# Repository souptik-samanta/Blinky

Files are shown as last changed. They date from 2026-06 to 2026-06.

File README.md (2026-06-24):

# Blinky Board

Made by Souptik!

I built this little project because I wanted a heart-shaped PCB that I could gift to someone. It's a simple LED chaser built around a 555 timer and a CD4017 decade counter. The LEDs light up one after another, creating a blinking animation around the heart.

Built using parts I already had on hand, and manufactured through JLC thanks stasis.
BUILD PHOTO


and here is the bottom



worknig video 

https://youtube.com/shorts/QsSJmAaTk8Q?feature=share
## Photos

Blinky Board PCB

Blinky Board Schematic

Blinky Board PCB Layout

Blinky Board Render

## How It Works

A 555 timer is configured as an oscillator that generates clock pulses. These pulses are fed into a CD4017 decade counter, which turns on one output at a time. Each output drives an LED on the heart, creating a rotating blinking effect. The potentiometer can be adjusted to change the animation speed.

## Bill of Materials (BoM)

| Part | Purpose | Quantity |
|---|---|---|
| PCB | Heart-shaped board that holds all the components | 1 |
| LED | Creates the chasing light effect around the heart | 10 |
| 1kΩ Resistor | Helps set the oscillator timing | 1 |
| 470Ω Resistor | Limits LED current | 1 |
| Potentiometer (RV) | Adjusts the animation speed | 1 |
| 1µF Capacitor | Works with the 555 timer to generate clock pulses | 1 |
| 1x01 Header | Test/debug connection point | 1 |
| 1x02 Header | Power input connector | 1 |
| CD4017 | Sequences the LEDs one after another | 1 |
| NE555P | Generates the clock signal | 1 |

## Cost

All components were sourced from my existing parts inventory, so the project itself cost me nothing to assemble.

| Item | Cost (USD) |
|---|---|
| Components | $0.00 |
| PCB | JLC sponser |
| **Total Out-of-Pocket Cost** | **$0.00** |

## Why I Made It

I wanted to make something small, simple, and fun that could be gifted to someone. Instead of a regular rectangular PCB, I designed it in the shape of a heart and added a classic 555 + 4017 LED chaser circuit to make it feel a bit more special.

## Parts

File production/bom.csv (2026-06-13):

Designator | Footprint | Quantity | Value | LCSC Part #
C1 | CP_Radial_D5.0mm_P2.50mm | 1 | 100uF
C2 | C_Disc_D4.7mm_W2.5mm_P5.00mm | 1 | 0.1uF
D1, D10, D2, D3, D4, D5, D6, D7, D8, D9 | LED_D5.0mm | 10 | LED
J1 | PinSocket_1x02_P2.54mm_Vertical | 1 | Conn_01x02_Pin
R1 | R_Axial_DIN0207_L6.3mm_D2.5mm_P7.62mm_Horizontal | 1 | R
R2 | R_Axial_DIN0207_L6.3mm_D2.5mm_P7.62mm_Horizontal | 1 | 470
RV1 | Potentiometer_Vishay_T93YA_Vertical | 1 | R_Potentiometer
U1 | DIP-16_W7.62mm_LongPads | 1 | 4017
U2 | DIP-8_W7.62mm_LongPads | 1 | NE555P

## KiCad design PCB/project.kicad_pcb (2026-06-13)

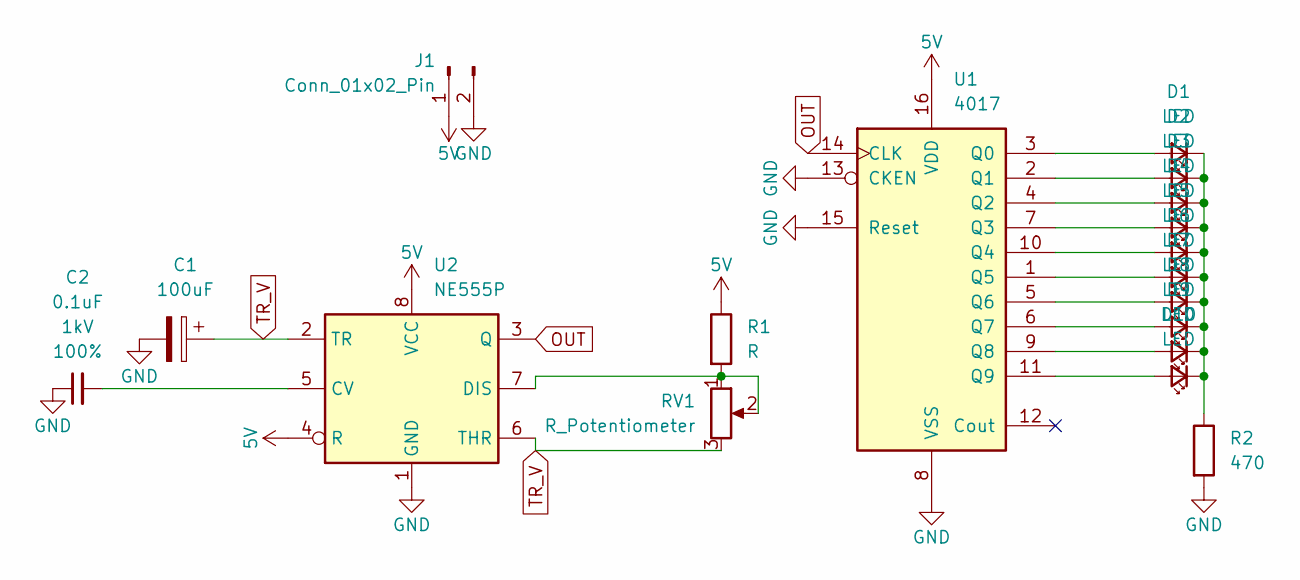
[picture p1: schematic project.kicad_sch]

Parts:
C1: 100uF; CP_Radial_D5.0mm_P2.50mm
C2: 0.1uF; C_Disc_D4.7mm_W2.5mm_P5.00mm; Voltage 1kV; Tolerance 100%
D1, D2, D3, D4, D5, D6, D7, D8, D9, D10: LED; LED_D5.0mm
J1: Conn_01x02_Pin; PinSocket_1x02_P2.54mm_Vertical
R1: R; R_Axial_DIN0207_L6.3mm_D2.5mm_P7.62mm_Horizontal
R2: 470; R_Axial_DIN0207_L6.3mm_D2.5mm_P7.62mm_Horizontal
RV1: R_Potentiometer; Potentiometer_Vishay_T93YA_Vertical
U1: 4017; DIP-16_W7.62mm_LongPads
U2: NE555P; DIP-8_W7.62mm_LongPads

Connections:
5V: J1.1, R1.1, U1.16 (VDD), U2.4 (R), U2.8 (VCC)
GND: C1.2, C2.1, J1.2, R2.2, U1.8 (VSS), U1.13 (CKEN), U1.15 (Reset), U2.1 (GND)
unnamed: D1.2 (A), U1.3 (Q0)
unnamed: D1.1 (K), D2.1 (K), D3.1 (K), D4.1 (K), D5.1 (K), D6.1 (K), D7.1 (K), D8.1 (K), D9.1 (K), D10.1 (K), R2.1
unnamed: D2.2 (A), U1.2 (Q1)
unnamed: D3.2 (A), U1.4 (Q2)
unnamed: D4.2 (A), U1.7 (Q3)
unnamed: D5.2 (A), U1.10 (Q4)
unnamed: D6.2 (A), U1.1 (Q5)
unnamed: D7.2 (A), U1.5 (Q6)
unnamed: D8.2 (A), U1.6 (Q7)
unnamed: D9.2 (A), U1.9 (Q8)
unnamed: D10.2 (A), U1.11 (Q9)
unnamed: C2.2, U2.5 (CV)
unnamed: R1.2, RV1.1, RV1.2, U2.7 (DIS)
OUT: U1.14 (CLK), U2.3 (Q)
TR_V: C1.1, RV1.3, U2.2 (TR), U2.6 (THR)

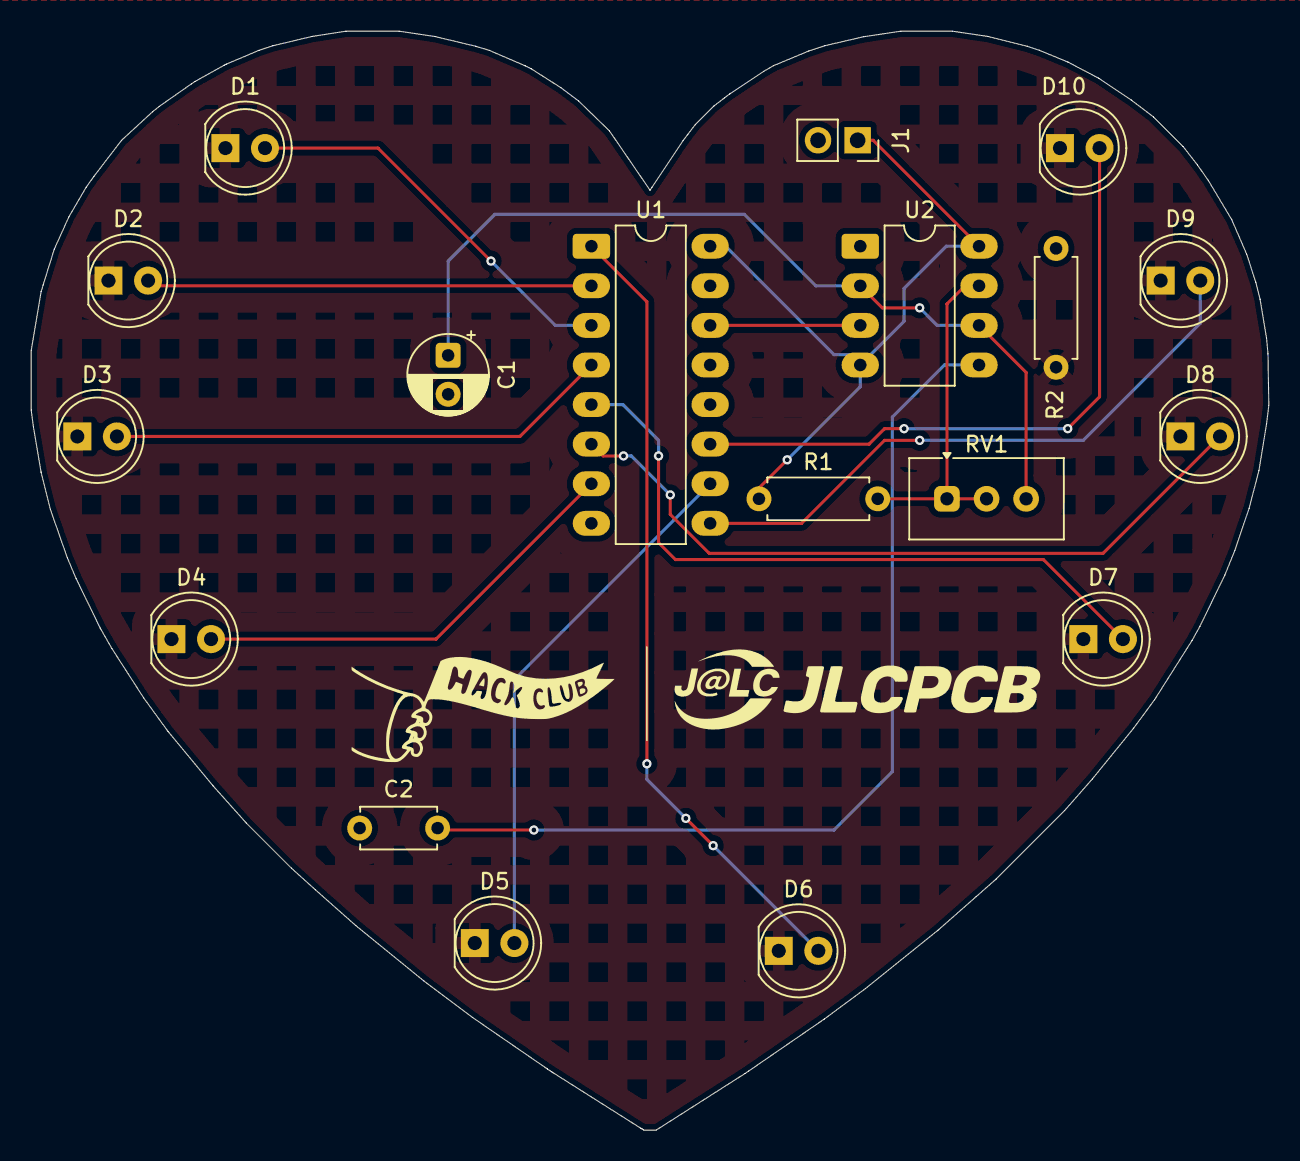
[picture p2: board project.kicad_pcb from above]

Board: 2 copper layers, 79.4 x 70.5 mm, 18 parts (0 on the bottom side), 17 nets.

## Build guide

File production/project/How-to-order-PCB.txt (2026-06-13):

How to Order PCB

Please refer to:
https://prodocs.easyeda.com/en/pcb/order-order-pcb/index.html
